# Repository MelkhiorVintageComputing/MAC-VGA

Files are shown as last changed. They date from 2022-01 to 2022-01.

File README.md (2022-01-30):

# Mac (vintage) to VGA adapter

To plug a VGA monitor on a vintage Mac with the DB15 connector.

See https://github.com/sfiera/mactech/blob/master/displays.rst for a lot of informations on the subject.

This was designed for my own use, the only goal was 'easy to solder'. Includes a basic 3D-printed two-parts shell to protect the adapter.

Works for me to get all possible resolutions on both a Quadra 650 and a LC III.

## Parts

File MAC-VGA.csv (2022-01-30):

Part/Designator | Manufacture Part Number/Seeed SKU | Quantity | URL
D1,D2 | 1N4148 | 2
SW2 | 210-2MS | 1
SW1 | 210-4MS | 1
C3 | 860021373002 | 1
J2 | L717SDA15PA4CH4R | 1
J1 | L77HDE15SD1CH4RHNVGA | 1 | https://www.mouser.fr/ProductDetail/Amphenol-Commercial-Products/L77HDE15SD1CH4RHNVGA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
R9 | MFR50SFTE52-1M | 1 | https://www.lcsc.com/product-detail/Chip-Resistor-Surface-Mount_UNI-ROYAL-Uniroyal-Elec-AS03W4J0105T5E_C966202.html

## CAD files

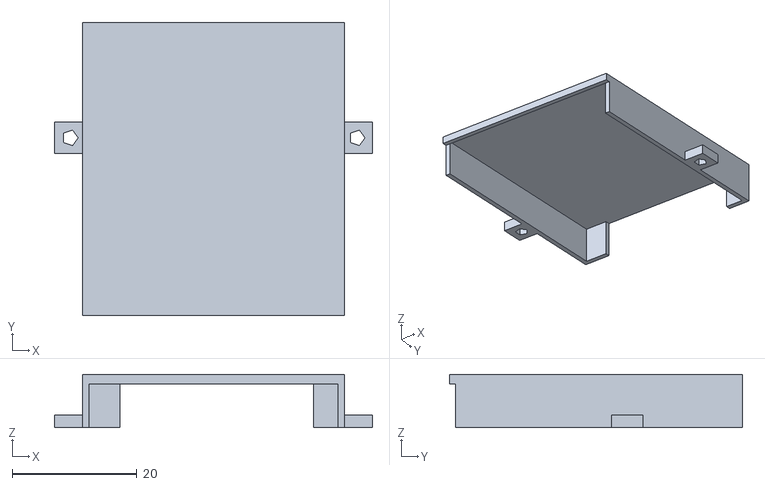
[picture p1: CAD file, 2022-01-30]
top.stl
51.0 x 47.0 x 8.50

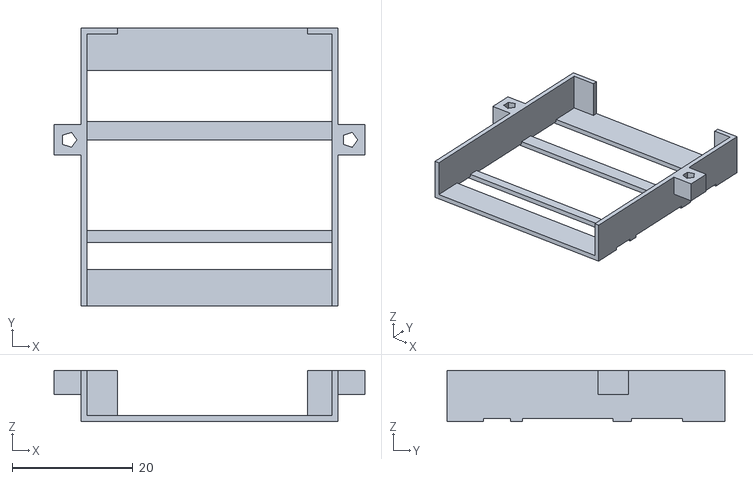
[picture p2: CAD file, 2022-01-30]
bottom.stl
51.5 x 46.0 x 8.50

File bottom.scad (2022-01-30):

WIDTH=40.5;
LENGTH=45;
WALL_THICKNESS=1;
WALL_LENGTH_1=45;//32.5;
WALL_LENGTH_2=4;
WALL_HEIGHT=8;

SCREW_SUPPORT_SIZE=5;
SCREW_SUPPORT_OFFSET=5;
SCREW_RADIUS=2.6/2;

module bottom() {
    difference() {
    union() {
    //translate([0,0,-WALL_THICKNESS/2]) cube([WIDTH+2*WALL_THICKNESS, LENGTH+2*WALL_THICKNESS, WALL_THICKNESS], center=true);
        
    translate([0,-(7/2)+LENGTH/2+WALL_THICKNESS,-WALL_THICKNESS/2]) cube([WIDTH+2*WALL_THICKNESS, 7, WALL_THICKNESS], center=true);
        
    translate([0,(6/2)-LENGTH/2,-WALL_THICKNESS/2]) cube([WIDTH+2*WALL_THICKNESS, 6, WALL_THICKNESS], center=true);
        
    translate([0,-11,-WALL_THICKNESS/2]) cube([WIDTH+2*WALL_THICKNESS, 2, WALL_THICKNESS], center=true);
        
    translate([0,6.5,-WALL_THICKNESS/2]) cube([WIDTH+2*WALL_THICKNESS, 3, WALL_THICKNESS], center=true);
        
    /* right and left */
    translate([+(WIDTH+WALL_THICKNESS)/2,(LENGTH-WALL_LENGTH_1)/2+WALL_THICKNESS/2,WALL_HEIGHT/2-WALL_THICKNESS/2]) cube([WALL_THICKNESS, WALL_LENGTH_1+WALL_THICKNESS, WALL_HEIGHT], center=true);
    
    translate([-(WIDTH+WALL_THICKNESS)/2,(LENGTH-WALL_LENGTH_1)/2+WALL_THICKNESS/2,WALL_HEIGHT/2-WALL_THICKNESS/2]) cube([WALL_THICKNESS, WALL_LENGTH_1+WALL_THICKNESS, WALL_HEIGHT], center=true);
    
    /* back */
    translate([-(WIDTH-WALL_LENGTH_2)/2+WALL_THICKNESS/2,(LENGTH+WALL_THICKNESS)/2, WALL_HEIGHT/2-WALL_THICKNESS/2]) cube([WALL_LENGTH_2+WALL_THICKNESS, WALL_THICKNESS, WALL_HEIGHT], center=true);
    
    translate([+(WIDTH-WALL_LENGTH_2)/2+WALL_THICKNESS/2,(LENGTH+WALL_THICKNESS)/2, WALL_HEIGHT/2-WALL_THICKNESS/2]) cube([WALL_LENGTH_2+WALL_THICKNESS, WALL_THICKNESS, WALL_HEIGHT], center=true);
    
    /* screw support */
    translate([-(WIDTH/2+WALL_THICKNESS/2+SCREW_SUPPORT_SIZE/2), SCREW_SUPPORT_OFFSET, WALL_HEIGHT/4+WALL_HEIGHT/2-WALL_THICKNESS/2]) cube([SCREW_SUPPORT_SIZE, SCREW_SUPPORT_SIZE, WALL_HEIGHT/2], center=true);
    translate([+(WIDTH/2+WALL_THICKNESS/2+SCREW_SUPPORT_SIZE/2), SCREW_SUPPORT_OFFSET, WALL_HEIGHT/4+WALL_HEIGHT/2-WALL_THICKNESS/2]) cube([SCREW_SUPPORT_SIZE, SCREW_SUPPORT_SIZE, WALL_HEIGHT/2], center=true);
    }
    union() {
    translate([-(WIDTH/2+WALL_THICKNESS/2+SCREW_SUPPORT_SIZE/2), SCREW_SUPPORT_OFFSET, WALL_HEIGHT/4+WALL_HEIGHT/2-WALL_THICKNESS/2]) cylinder(h=50, r1=SCREW_RADIUS, r2=SCREW_RADIUS, center=true);
    translate([+(WIDTH/2+WALL_THICKNESS/2+SCREW_SUPPORT_SIZE/2), SCREW_SUPPORT_OFFSET, WALL_HEIGHT/4+WALL_HEIGHT/2-WALL_THICKNESS/2]) cylinder(h=50, r1=SCREW_RADIUS, r2=SCREW_RADIUS, center=true);
    }
}
}


bottom();

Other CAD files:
top.scad

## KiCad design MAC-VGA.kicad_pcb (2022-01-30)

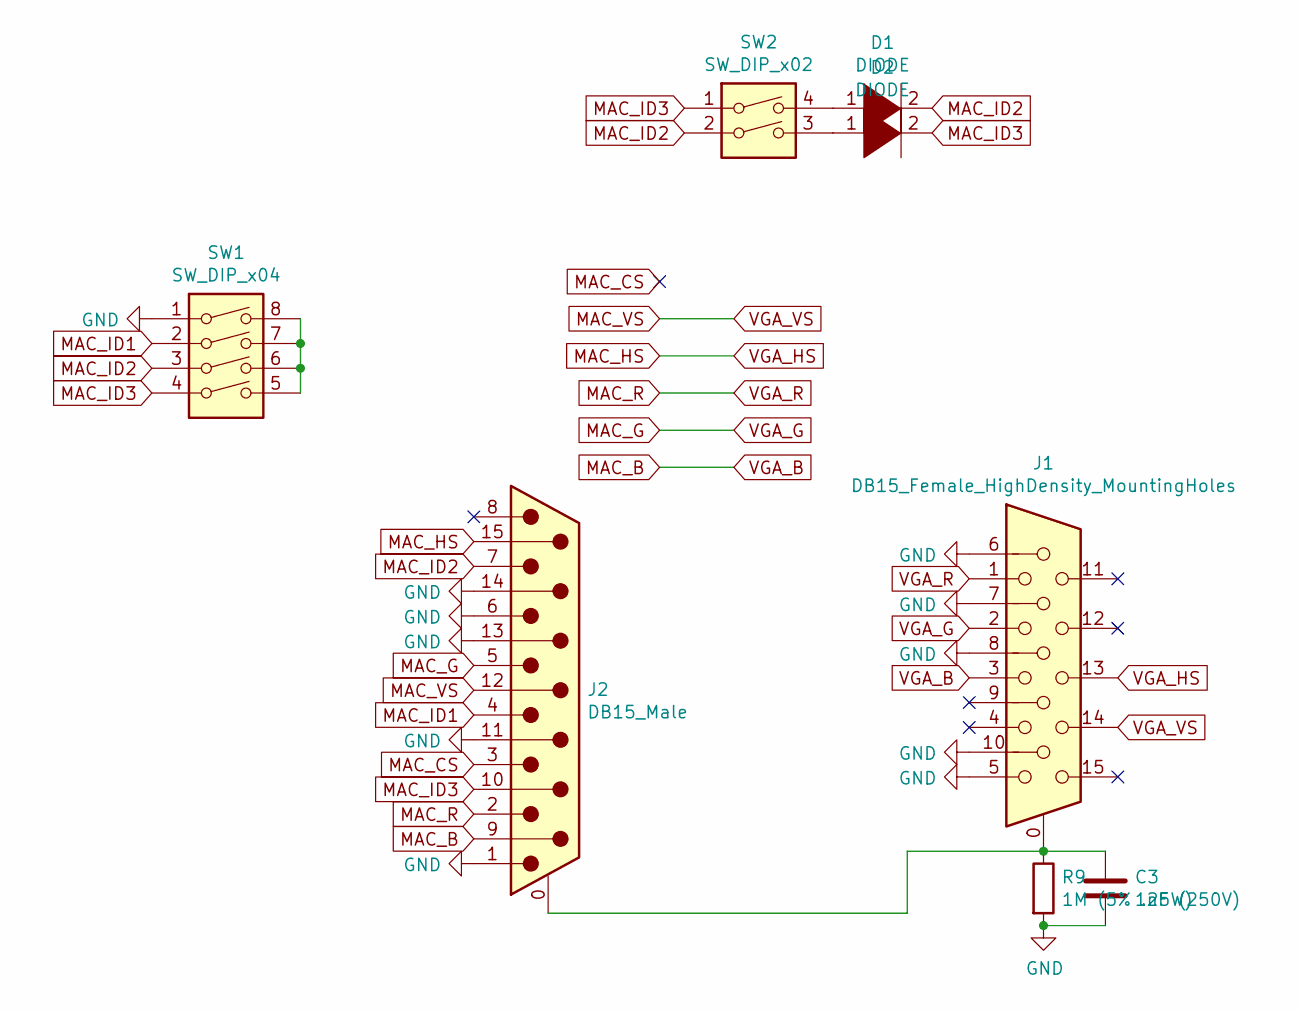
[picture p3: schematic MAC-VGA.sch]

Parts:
C3: 1nF (250V); CP_Radial_D6.3mm_P2.50mm; MPN 860021373002
D1, D2: DIODE; D_DO-35_SOD27_P2.54mm_Vertical_AnodeUp; MPN 1N4148
J1: DB15_Female_HighDensity_MountingHoles; L77HDE15SD1CH4RHNVGA; MPN L77HDE15SD1CH4RHNVGA
J2: DB15_Male; DSUB-15_Male_Horizontal_P2.77x2.84mm_EdgePinOffset7.70mm_Ho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; MPN L717SDA15PA4CH4R
R9: 1M (5% .25W); R_Axial_DIN0207_L6.3mm_D2.5mm_P2.54mm_Vertical; MPN MFR50SFTE52-1M
SW1: SW_DIP_x04; SW_DIP_SPSTx04_Slide_6.7x11.72mm_W7.62mm_P2.54mm_LowProfile; MPN 210-4MS
SW2: SW_DIP_x02; SW_DIP_SPSTx02_Slide_6.7x6.64mm_W7.62mm_P2.54mm_LowProfile; MPN 210-2MS

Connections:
GND: C3.2, J1.5, J1.6, J1.7, J1.8, J1.10, J2.1, J2.6, J2.11 (P111), J2.13, J2.14, R9.2, SW1.1
MAC_B: J1.3, J2.9
MAC_CS: J2.3
MAC_G: J1.2, J2.5
MAC_HS: J1.13, J2.15
MAC_ID1: J2.4, SW1.2
MAC_ID2: D1.2 (A), J2.7, SW1.3, SW2.2
MAC_ID3: D2.2 (A), J2.10, SW1.4, SW2.1
MAC_R: J1.1, J2.2
MAC_VS: J1.14, J2.12
unnamed: C3.1, J1.0, J2.0 (PAD), R9.1
unnamed: D1.1 (K), SW2.4
unnamed: D2.1 (K), SW2.3
unnamed: SW1.5, SW1.6, SW1.7, SW1.8

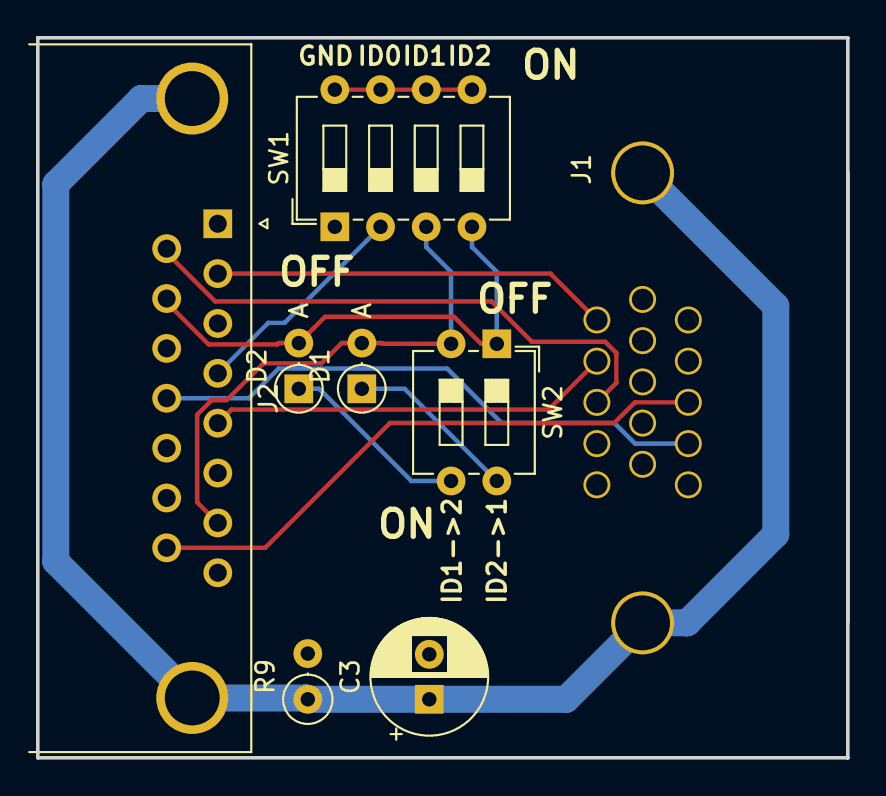
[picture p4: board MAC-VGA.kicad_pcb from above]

Board: 2 copper layers, 45.0 x 40.0 mm, 8 parts (0 on the bottom side), 13 nets.
